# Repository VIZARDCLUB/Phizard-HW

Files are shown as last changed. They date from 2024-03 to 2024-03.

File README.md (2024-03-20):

# Phizard-HW

The Phizard board is licensed under CERN Open Hardware Licence Version 2 - Strongly Reciprocal.  
This means that any changes made to the board should be made public and CHANGES.txt be updated to reflect said changes.  

The Phizard Link-V board is licensed under GPL-3.0 licence.  

Phizard has some added features based on PhobGCC 2.0.5.  
Currently works with [PhoZL](https://github.com/sean44104/PhoZL) firmware.  
  
  
  
  

# CHANGES.txt
- Original pad footprint for ABXY. Support 2pin DIP switches. Added holes for D2LS switches.  
- Original pad footprint for D-pad. Support SMD tact switches, D2LS switches and 2pin DIP switches.  
- Added thin tactile switch support to the START button.  
- Swap USB connecter to USB-C.  
- Added ZL button connected to GPIO12. Works with PhoZL firmware.  
- Fixed the Z/ZL footprint to fit right angle mouse switches.  
- Added breakout pad for Dup and Dleft for SoreiruFactory's Double LR Trigger.
- Added a 22ohm resister and a pad for 3.3V cell rumble.  
- Added Phizard Link-V based on OlyU-V. This supports Phob vision output. (I will make an adapter for it in the future.)
- PH connector can be used for LR pad without shell trimming

# Parts example
[H5.2mm Square micro switch](https://a.aliexpress.com/_on09e08) for ABXY and D-pad  
[D2LS-11](https://mou.sr/3ILtBsM) and the other switches that uses the same footprint for ABXY and Dpad  
[SKRRAAE010](https://mou.sr/3PtAZNg) and GBASP start button rubber for start (The edited shell will be published after tested)  

# Credit
## Main board
https://github.com/PhobGCC/PhobGCCv2-HW  
https://github.com/sean44104/phozl  

## USB features
https://github.com/Crane1195/Model-U  
https://github.com/sean44104/OlyU  
https://github.com/rana-sylvatica/OlyU-V

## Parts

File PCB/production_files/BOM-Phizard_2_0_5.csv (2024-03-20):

Comment | Designator | Footprint | LCSC
5.1k | R23,R26,R27,R28 | R_0402_1005Metric | C105872
1k | R16,R18 | C_0402_1005Metric | C11702
47u | C1 | CP_EIA-3528-12_Kemet-T_Pad1.50x2.35mm_HandSolder | C136751
CUS10S30,H3F | D1,D5 | D_SOD-323 | C146335
Q_PMOS_GDS | Q2 | SOT-23 | C15127
100n | C17,C19,C20,C22,C24,C25,C26,C27,C28,C29,C30,C31,C32 | C_0402_1005Metric | C1525
27p | C14,C15 | C_0402_1005Metric | C1557
10u | C16,C18 | C_0805_2012Metric | C15850
316 | R10,R19,R24,R25 | R_0402_1005Metric | C159037
0.047u | C3,C4,C5,C6,C7,C8 | C_0603_HandSoldering | C1622
RP2040 | U8 | RP2040-QFN-56 | C2040
Q_NMOS_GSD | Q1,Q3 | SOT-23 | C20917
100R | R11,R12 | R_0603_1608Metric_Pad0.98x0.95mm_HandSolder | C22775
2k | R3,R4,R5,R6 | R_0603_1608Metric_Pad0.98x0.95mm_HandSolder | C22975
27 | R20,R21 | C_0402_1005Metric | C25100
10k | R13,R14,R15 | R_0603_1608Metric_Pad0.98x0.95mm_HandSolder | C25804
DRV5055A3xDBZxQ1 | U10,U11,U4,U9 | SOT-23 | C266128
USBLC6-2P6 | U12,U13 | SOT-666 | C2827693
22R | R22 | R_1206_3216Metric | C2845146
BOOTSEL | S1 | SW_TS-1187A-B-A-B | C318884
180 | R1,R2,R7,R8,R9 | R_0402_1005Metric | C38941
Crystal_GND24 | Y1 | Crystal_SMD_3225-4Pin_3.2x2.5mm | C403945
USB_C_Receptacle | J12 | Shou Han Type-C 24P QCHT | C456013
1u | C21,C23 | C_0402_1005Metric | C52923
MCP3202 | U1,U3 | SOIC-8_3.9x4.9mm_P1.27mm | C56997
AMS1117-3.3 | U6 | SOT-223-3_TabPin2 | C6186
Fuse | F1 | Fuse_1206_3216Metric | C69680
M7C | D2 | D_SOD-123 | C8598
USB_C_Receptacle_USB2.0 | J9 | USB_C_Receptacle_G-Switch_GT-USB-7010ASV | C963412
W25Q128JVS | U7 | SOIC-8_5.23x5.23mm_P1.27mm | C97521

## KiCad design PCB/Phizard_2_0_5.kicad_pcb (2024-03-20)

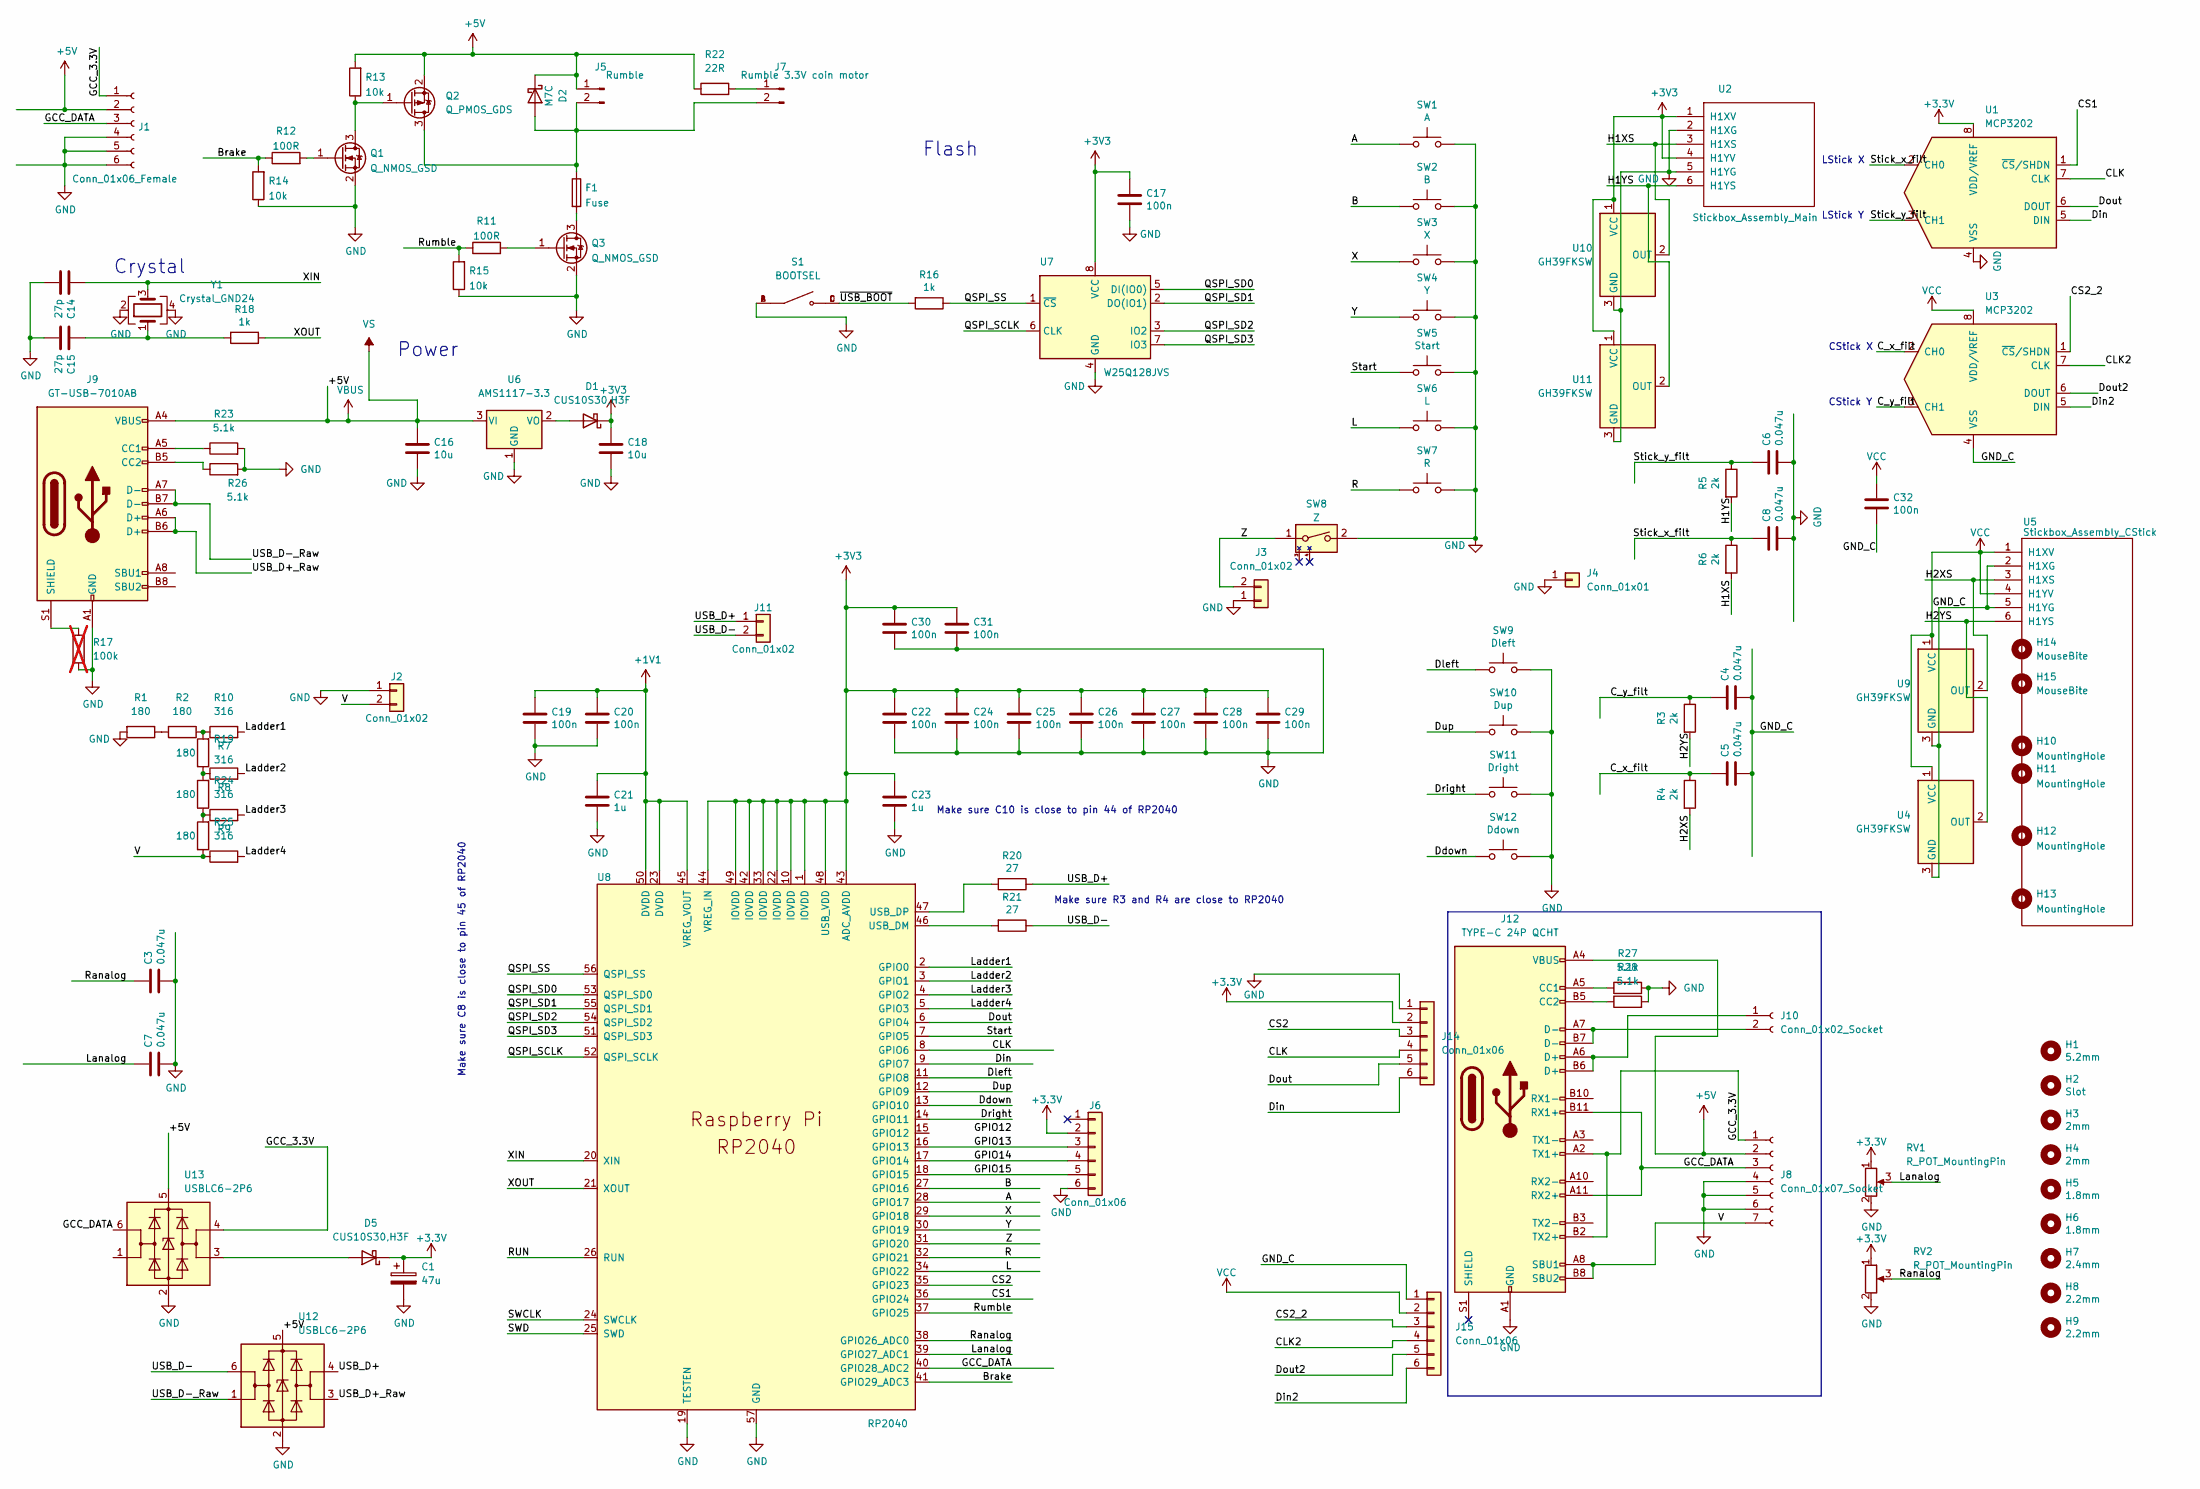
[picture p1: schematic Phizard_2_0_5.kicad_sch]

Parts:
C1: 47u; CP_EIA-3528-12_Kemet-T_Pad1.50x2.35mm_HandSolder; LCSC C136751
C3, C4, C5, C6, C7, C8: 0.047u; C_0603_HandSoldering; LCSC C1622
C14, C15: 27p; C_0402_1005Metric; LCSC C1557
C16, C18: 10u; C_0805_2012Metric; LCSC C15850
C17, C19, C20, C22, C24, C25, C26, C27, C28, C29, C30, C31, C32: 100n; C_0402_1005Metric; LCSC C1525
C21, C23: 1u; C_0402_1005Metric; LCSC C52923
D1, D5: CUS10S30,H3F; D_SOD-323; LCSC C146335
D2: M7C; D_SOD-123; LCSC C8598
F1: Fuse; Fuse_1206_3216Metric; LCSC C69680
H1: 5.2mm; MountingHole_5.2mm
H2: Slot
H3, H4: 2mm; MountingHole_2.0mm
H5, H6: 1.8mm; MountingHole_1.8mm
H7: 2.4mm; MountingHole_2.4mm
H8, H9: 2.2mm; MountingHole_2.2mm
H10: MountingHole; MountingHole_1.8mm
H11: MountingHole; MountingHole_5.2mm
H12, H13: MountingHole; MountingHole_2.0mm
H14: MouseBite; breakaway-mousebites-double-v2-small
H15: MouseBite; breakaway-mousebites-double-v2-large
J1: Conn_01x06_Female; GCC_Header_Straight_1x06_Pitch2.00mm
J2, J11: Conn_01x02; PinHeader_1x02_P2.00mm_Vertical
J3: Conn_01x02; PinHeader_1x02_P2.00mm_Horizontal
J4: Conn_01x01; PinHeader_1x01_P2.54mm_Vertical
J5: Rumble; rumble_pins
J6, J14, J15: Conn_01x06; PinSocket_1x06_P2.00mm_Vertical
J7: Rumble 3.3V coin motor; rumble_pins
J8: Conn_01x07_Socket
J9: GT-USB-7010AB; USB_C_Receptacle_G-Switch_GT-USB-7010ASV; LCSC C963412
J10: Conn_01x02_Socket
J12: TYPE-C 24P QCHT; LCSC C456013
Q1, Q3: Q_NMOS_GSD; SOT-23; LCSC C20917
Q2: Q_PMOS_GDS; SOT-23; LCSC C15127
R1, R2, R7, R8, R9: 180; R_0402_1005Metric; LCSC C38941
R3, R4, R5, R6: 2k; R_0603_1608Metric_Pad0.98x0.95mm_HandSolder; LCSC C22975
R10, R19, R24, R25: 316; R_0402_1005Metric; LCSC C159037
R11, R12: 100R; R_0603_1608Metric_Pad0.98x0.95mm_HandSolder; LCSC C22775
R13, R14, R15: 10k; R_0603_1608Metric_Pad0.98x0.95mm_HandSolder; LCSC C25804
R16, R18: 1k; C_0402_1005Metric; LCSC C11702
R17: 100k; R_0603_1608Metric_Pad0.98x0.95mm_HandSolder; LCSC C25803; not fitted
R20, R21: 27; C_0402_1005Metric; LCSC C25100
R22: 22R; R_1206_3216Metric; LCSC C2845146
R23, R26, R27, R28: 5.1k; R_0402_1005Metric; LCSC C105872
RV1, RV2: R_POT_MountingPin; GCC_Slider
S1: BOOTSEL; SW_TS-1187A-B-A-B; PARTREV A0; LCSC C318884
SW1: A; ABXY_Contact_Omron_Switch_Circley
SW2: B; ABXY_Contact_Omron_Switch_Circley
SW3: X; ABXY_Contact_Omron_Switch_Circley
SW4: Y; ABXY_Contact_Omron_Switch_Circley
SW5: Start; Start_Contact
SW6: L; Pin_Header_Straight_1x02_Pitch2.54mm
SW7: R; Pin_Header_Straight_1x02_Pitch2.54mm
SW8: Z; Z_Switch_Edge_Omron
SW9: Dleft; Dpad_Contact_TL3315NF_2_ZigZag
SW10: Dup; Dpad_Contact_TL3315NF_2_ZigZag
SW11: Dright; Dpad_Contact_TL3315NF_2_ZigZag
SW12: Ddown; Dpad_Contact_TL3315NF_2_ZigZag
U1, U3: MCP3202; SOIC-8_3.9x4.9mm_P1.27mm; LCSC C56997
U2: Stickbox_Assembly_Main; GCC_Stickbox_Hall_Only
U4, U9, U10, U11: GH39FKSW; SOT-23; LCSC C266128
U5: Stickbox_Assembly_CStick; GCC_Stickbox_Hall_Only
U6: AMS1117-3.3; SOT-223-3_TabPin2; LCSC C6186
U7: W25Q128JVS; SOIC-8_5.23x5.23mm_P1.27mm; LCSC C97521
U8: RP2040; RP2040-QFN-56; LCSC C2040
U12, U13: USBLC6-2P6; SOT-666; LCSC C2827693
Y1: Crystal_GND24; Crystal_SMD_3225-4Pin_3.2x2.5mm; LCSC C403945

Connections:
+1V1: C19.1, C20.1, C21.1, U8.23 (DVDD), U8.45 (VREG_VOUT), U8.50 (DVDD)
+5V: C16.1, D2.1 (K), J1.2, J5.1, J8.2, J9.A4 (VBUS), J9.A9 (VBUS), J9.B4 (VBUS), J9.B9 (VBUS), J12.A4 (VBUS), J12.A9 (VBUS), J12.B4 (VBUS), J12.B9 (VBUS), Q2.2 (S), R13.2, R22.1, U6.3 (VI), U12.5 (VBUS), U13.5 (VBUS)
/A: SW1.1, U8.28 (GPIO17)
/B: SW2.1, U8.27 (GPIO16)
/Brake: R12.1, R14.2, U8.41 (GPIO29_ADC3)
/CLK: J14.4, U1.7 (CLK), U8.8 (GPIO6)
/CLK2: J15.4, U3.7 (CLK)
/CS1: U1.1 (~CS/SHDN), U8.36 (GPIO24)
/CS2: J14.3, U8.35 (GPIO23)
/CS2_2: J15.3, U3.1 (~CS/SHDN)
/C_x_filt: C5.1, R4.1, U3.2 (CH0)
/C_y_filt: C4.1, R3.1, U3.3 (CH1)
/Ddown: SW12.1, SW12.3, SW12.5, U8.13 (GPIO10)
/Din: J14.6, U1.5 (DIN), U8.9 (GPIO7)
/Din2: J15.6, U3.5 (DIN)
/Dleft: SW9.1, SW9.3, SW9.5, U8.11 (GPIO8)
/Dout: J14.5, U1.6 (DOUT), U8.6 (GPIO4)
/Dout2: J15.5, U3.6 (DOUT)
/Dright: SW11.1, SW11.3, SW11.5, U8.14 (GPIO11)
/Dup: SW10.1, SW10.3, SW10.5, U8.12 (GPIO9)
/GCC_3.3V: J1.1, J8.1, J12.A2 (TX1+), J12.B2 (TX2+), U13.4 (I/O2)
/GCC_DATA: J1.3, J8.3, J12.A11 (RX2+), J12.B11 (RX1+), U8.40 (GPIO28_ADC2), U13.6 (I/O1)
/GND_C: C4.2, C5.2, C32.2, J15.1, U3.4 (VSS), U4.3 (GND), U5.2 (H1XG), U5.5 (H1YG), U9.3 (GND)
/GPIO12: U8.15 (GPIO12); also elsewhere on the board
/GPIO13: J6.3, U8.16 (GPIO13)
/GPIO14: J6.4, U8.17 (GPIO14)
/GPIO15: J6.5, U8.18 (GPIO15)
/H1XS: R6.2, U2.3 (H1XS), U10.2 (OUT)
/H1YS: R5.2, U2.6 (H1YS), U11.2 (OUT)
/H2XS: R4.2, U5.3 (H1XS), U9.2 (OUT)
/H2YS: R3.2, U4.2 (OUT), U5.6 (H1YS)
/L: SW6.1, U8.34 (GPIO22)
/Ladder1: R10.2, U8.2 (GPIO0)
/Ladder2: R19.2, U8.3 (GPIO1)
/Ladder3: R24.2, U8.4 (GPIO2)
/Ladder4: R25.2, U8.5 (GPIO3)
/Lanalog: C7.1, RV1.3 (Signal), U8.39 (GPIO27_ADC1)
/QSPI_SCLK: U7.6 (CLK), U8.52 (QSPI_SCLK)
/QSPI_SD0: U7.5 (DI(IO0)), U8.53 (QSPI_SD0)
/QSPI_SD1: U7.2 (DO(IO1)), U8.55 (QSPI_SD1)
/QSPI_SD2: U7.3 (IO2), U8.54 (QSPI_SD2)
/QSPI_SD3: U7.7 (IO3), U8.51 (QSPI_SD3)
/QSPI_SS: R16.1, U7.1 (~CS), U8.56 (QSPI_SS)
/R: SW7.1, U8.32 (GPIO21)
/RUN: U8.26 (RUN)
/Ranalog: C3.1, RV2.3 (Signal), U8.38 (GPIO26_ADC0)
/Rumble: R11.1, R15.2, U8.37 (GPIO25)
/SWCLK: U8.24 (SWCLK)
/SWD: U8.25 (SWD)
/Start: SW5.1, U8.7 (GPIO5)
/Stick_x_filt: C8.1, R6.1, U1.2 (CH0)
/Stick_y_filt: C6.1, R5.1, U1.3 (CH1)
/USB_D+_Raw: J9.A6 (D+), J9.B6 (D+), U12.3 (I/O2)
/USB_D-_Raw: J9.A7 (D-), J9.B7 (D-), U12.1 (I/O1)
/V: J1.7, J2.2, J8.7, J12.A8 (SBU1), J12.B8 (SBU2), R9.1, R25.1
/X: SW3.1, U8.29 (GPIO18)
/XIN: C14.1, U8.20 (XIN), Y1.3
/XOUT: R18.1, U8.21 (XOUT)
/Y: SW4.1, U8.30 (GPIO19)
/Z: J3.2, SW8.1, U8.31 (GPIO20)
/~USB_BOOT: R16.2, S1.C, S1.D
GND: C1.2, C3.2, C6.2, C7.2, C8.2, C14.2, C15.2, C16.2, C17.2, C18.2, C19.2, C20.2, C21.2, C22.2, C23.2, C24.2, C25.2, C26.2, C27.2, C28.2, C29.2, C30.2, C31.2, J1.4, J1.5, J1.6, J2.1, J3.1, J4.1, J6.6, J8.4, J8.5, J8.6, J9.A1 (GND), J9.A12 (GND), J9.B1 (GND), J9.B12 (GND), J12.A1 (GND), J12.A12 (GND), J12.B1 (GND), J12.B12 (GND), J14.1, Q1.2 (S), Q3.2 (S), R1.2, R14.1, R15.1, R17.2, R23.2, R26.2, R27.2, R28.2, RV1.2 (GND), RV2.2 (GND), S1.A, S1.B, SW1.2, SW2.2, SW3.2, SW4.2, SW5.2, SW6.2, SW7.2, SW8.2, SW9.2, SW9.4, SW9.6, SW10.2, SW10.4, SW10.6, SW11.2, SW11.4, SW11.6, SW12.2, SW12.4, SW12.6, U1.4 (VSS), U2.2 (H1XG), U2.5 (H1YG), U6.1 (GND), U7.4 (GND), U8.19 (TESTEN), U8.57 (GND), U10.3 (GND), U11.3 (GND), U12.2 (GND), U13.2 (GND), Y1.2, Y1.4; also elsewhere on the board
unnamed: C15.1, R18.2, Y1.1
unnamed: D1.2 (A), U6.2 (VO)
unnamed: D2.2 (A), F1.1, J5.2, J7.2, Q2.3 (D)
unnamed: D5.2 (A), U13.3 (I/O2)
unnamed: J7.1, R22.2
unnamed: J9.A5 (CC1), R23.1
unnamed: J9.B5 (CC2), R26.1
unnamed: J9.S1 (SHIELD), R17.1
unnamed: J12.A5 (CC1), R27.1
unnamed: J12.B5 (CC2), R28.1
unnamed: Q1.3 (D), Q2.1 (G), R13.1
unnamed: Q1.1 (G), R12.2
unnamed: F1.2, Q3.3 (D)
unnamed: Q3.1 (G), R11.2
unnamed: R1.1, R2.2
unnamed: R2.1, R7.2, R10.1
unnamed: R7.1, R8.2, R19.1
unnamed: R8.1, R9.2, R24.1
unnamed: R21.2, U8.46 (USB_DM)
unnamed: R20.2, U8.47 (USB_DP)
VCC: C32.1, J15.2, U3.8 (VDD/VREF), U4.1 (VCC), U5.1 (H1XV), U5.4 (H1YV), U9.1 (VCC)

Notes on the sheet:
Power
LStick Y
Make sure C10 is close to pin 44 of RP2040
CStick Y
Make sure R3 and R4 are close to RP2040
Make sure C8 is close to pin 45 of RP2040
Flash
Crystal
CStick X
LStick X

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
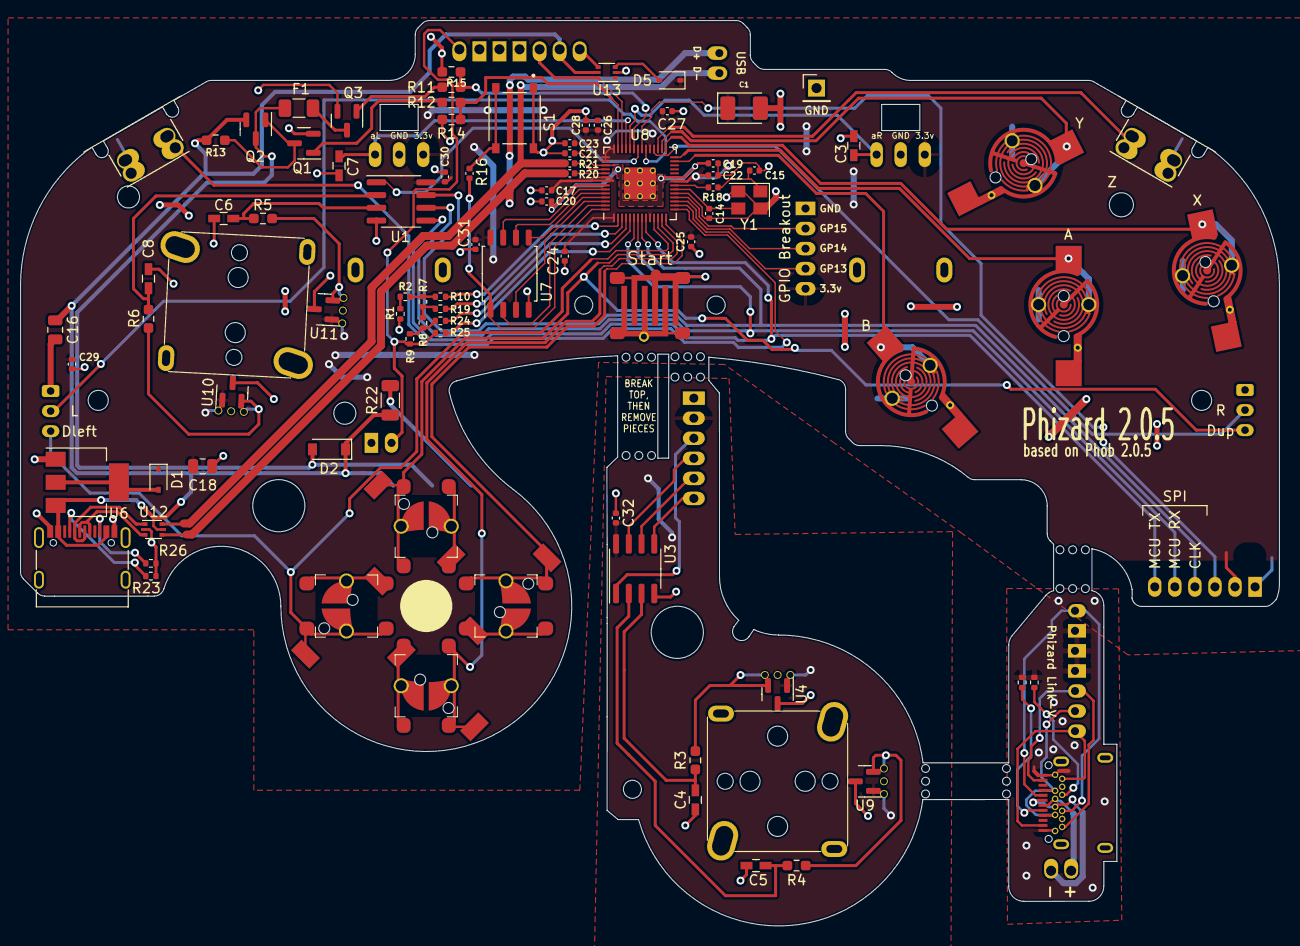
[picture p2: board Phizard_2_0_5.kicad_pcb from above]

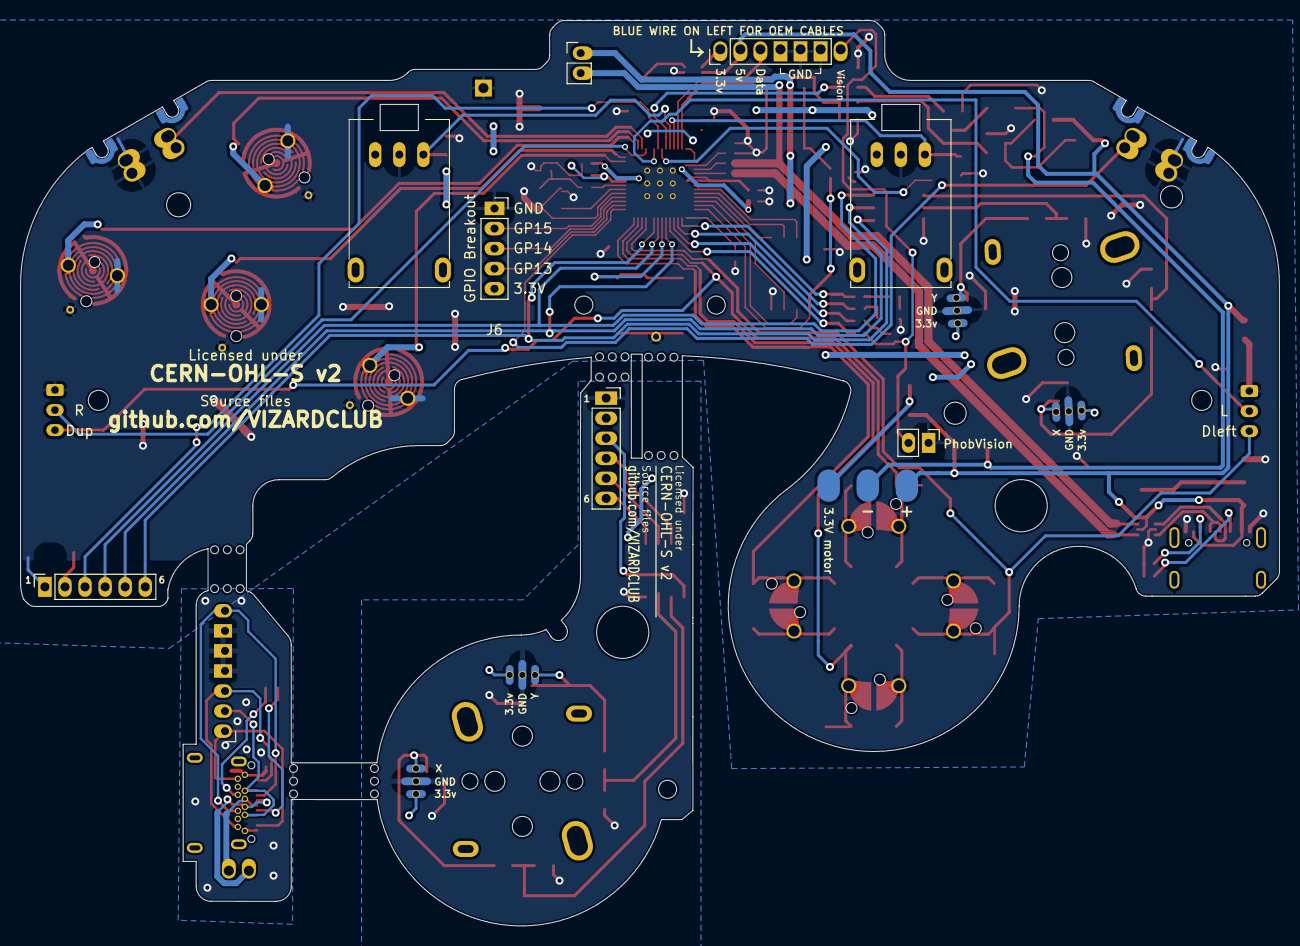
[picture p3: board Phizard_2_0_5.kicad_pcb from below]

Board: 2 copper layers, 125.5 x 90.3 mm, 122 parts (13 on the bottom side), 82 nets.

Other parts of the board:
H14#2, H14#3, H14#4, H14#5: MouseBite; breakaway-mousebites-double-v2-small
SW8#2: Z; Z_Switch_Edge_Omron

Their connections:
/GPIO12: SW8#2.2; also elsewhere on the board
GND: SW8#2.1; also elsewhere on the board

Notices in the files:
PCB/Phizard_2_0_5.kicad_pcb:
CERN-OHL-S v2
